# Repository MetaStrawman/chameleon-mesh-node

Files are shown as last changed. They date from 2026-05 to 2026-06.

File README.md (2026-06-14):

# Chameleon Mesh Node

> A rugged, dual-radio environmental telemetry node built on the Meshtastic + LoRa stack.

**Submission:** Seeed Studio Meshtastic Build-Off 2026
**Status:** Design complete & verified — routed, DRC-clean (0 errors / 0 unconnected; 31 cosmetic silkscreen/DFM warnings), Gerbers exported. **Pre-fabrication** (first article not yet ordered).
**Hardware revision:** v1.2
**License:** Multi-license open source — CERN-OHL-S-2.0 (hardware), GPL-3.0-or-later (Meshtastic firmware variant), MIT (tooling). See [`LICENSE`](LICENSE) and [`NOTICE.md`](NOTICE.md).

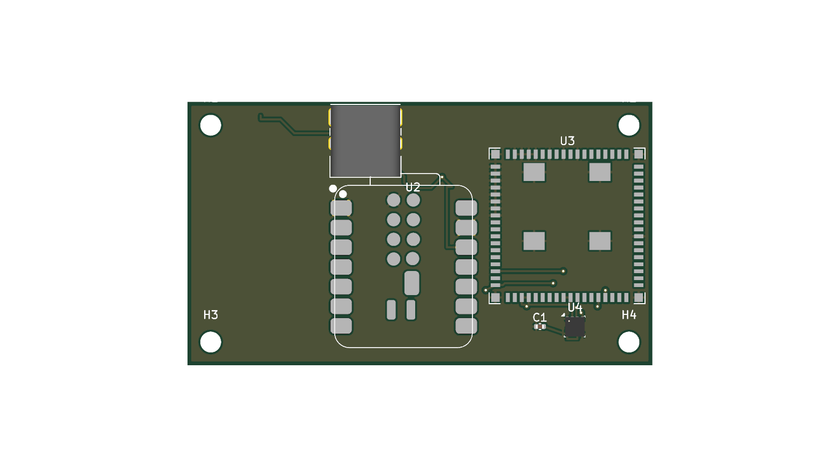
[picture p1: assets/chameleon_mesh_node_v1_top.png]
Chameleon Mesh Node v1.2 — top


*3D render (top). Bottom: [`assets/chameleon_mesh_node_v1_bottom.png`](assets/chameleon_mesh_node_v1_bottom.png).*

## What it is

The Chameleon Mesh Node is a single-board, USB-powered field appliance for Meshtastic telemetry. It joins a Meshtastic mesh on sub-GHz LoRa for resilient long-range messaging, reads local environment with an on-board sensor, and exposes a Wi-Fi / BLE side-channel for short-range provisioning and bulk-data offload.

Designed as a compact, regenerable two-radio Meshtastic reference board.

## Why dual radio

Most off-the-shelf Meshtastic nodes pick one path: a LoRa-only board that needs a phone to provision, or a Wi-Fi-only "smart sensor" that needs an AP within range. Neither survives a real off-grid deployment where the closest infrastructure is hours away.

This board pairs **two complementary radio subsystems on one PCB**:

| Subsystem | Role | Module |
|---|---|---|
| Long-range mesh | Meshtastic LoRa + GNSS time-sync + Wi-Fi scan for opportunistic uplink | Seeed **Wio-WM1110** (Semtech LR1110 + Nordic nRF52840) |
| Local-area + provisioning | Wi-Fi 6 / BLE 5 / 802.15.4 for setup, OTA, and bulk data offload to a passing operator's phone | Seeed **XIAO ESP32-C5** |

Both radios cohabit one 60×34 mm 2-layer board, with explicit RF zoning and a shared ground pour designed to keep mutual desense within acceptable limits for an environmental-sensing-class duty cycle.

## Top-level specs

| | |
|---|---|
| Dimensions | 60 × 34 mm, 2-layer FR-4 |
| MCU | Nordic nRF52840 (Meshtastic firmware host) + Espressif ESP32-C5 (companion) |
| Radios | Semtech LR1110 (sub-GHz LoRa, GNSS, passive Wi-Fi scan); Wi-Fi 6 / BLE 5 / 802.15.4 |
| Power input | USB-C 5 V (XIAO ESP32-C5 onboard port) |
| Environmental sensor | Bosch BME280 (temperature, humidity, barometric pressure, I²C) |
| Operating temperature | -20 °C to +60 °C (designed; pending environmental test) |

## Repository layout

```
chameleon_mesh_node/
├── README.md                — this file
├── LICENSE                  — multi-license map (see also LICENSES/, NOTICE.md)
├── LICENSES/                — full license texts (CERN-OHL-S-2.0, GPL-3.0, MIT)
├── NOTICE.md                — third-party attribution
├── SUBMISSION_CHECKLIST.md  — Build-Off submission readiness gate
├── assets/                  — 3D renders
├── docs/
│   ├── architecture.md      — block diagram, radio zoning, antenna feeds
│   ├── build-guide.md       — BOM, assembly notes, first-power-on checklist
│   └── power-design.md      — USB-C power input and module power tree
├── hardware/
│   ├── kicad/               — KiCad 10 project (schematic, PCB, footprints, gerber zips)
│   ├── gerbers/             — extracted v1.2 Gerbers + Excellon drill (fab-ready)
│   └── scripts/             — Python composers that regenerate schematic + PCB from source
├── firmware/                — Meshtastic nRF52840 variant (variant.h + platformio.ini) + ESP32-C5 stub
└── enclosure/cad/           — 3D-printable case (planned, post-fab)
```

The KiCad project is fully regenerable: `python3 hardware/scripts/build_schematic.py` rebuilds the schematic from the Python composer, and `python3 hardware/scripts/build_pcb.py` rebuilds the pre-placed PCB. You can wipe the `.kicad_*` files and reproduce the design from source.

## How it uses Meshtastic

The Chameleon Mesh Node **is a Meshtastic node.** The Nordic nRF52840 core of the
Wio-WM1110 runs the [Meshtastic firmware](https://github.com/meshtastic/firmware);
the Semtech LR1110 is its sub-GHz LoRa radio (plus GNSS time-sync and passive
Wi-Fi scan). It joins a Meshtastic mesh, announces itself, relays messages, and
publishes its BME280 environmental readings as Meshtastic telemetry — provisioned
over BLE with the standard Meshtastic mobile app.

Because the base board (Seeed Wio-WM1110 / nRF52840 + LR1110) is already supported
upstream, this project ships as an **incremental hardware variant**, not a new port.
The board-specific deltas (BME280 at I²C `0x76`, an ESP32-C5 companion-wake GPIO)
are captured in [`firmware/variant.h`](firmware/variant.h) +
[`firmware/platformio.ini`](firmware/platformio.ini), layered on the upstream
Wio-WM1110 build environment. See [`firmware/README.md`](firmware/README.md).

## Design state & verification

- Schematic ERC: **0 errors / 0 warnings** (KiCad 10).
- PCB: 2-layer routed (top-copper signal, bottom-copper VBUS detour with vias), 3 GND zones poured, RF-zoned placement.
- Post-route DRC: **0 errors / 0 unconnected / 31 warnings** (cosmetic silkscreen-over-pad, silk-to-edge, library-footprint, and one dangling-track advisory; non-blocking for fabrication — see `docs/design-rationale.md`).
- Gerbers + Excellon drill exported (`hardware/gerbers/`).
- v1.1 → v1.2: top edge truncated 60×40 → 60×34 mm so the USB-C mouth is flush with the board edge (the earlier board had the connector inset and the cable could not seat); the DNP BQ24074 charger (U1) and the LiPo connector (J2) were deleted (their dead VBAT traces shorted the relocated mounting hole), leaving the board USB-powered only; mounting holes relocated, routing and GND zones refilled.

## Status

The board is **design-complete and verified** — schematic + ERC clean, RF-zoned
placement, routing and ground pour done, DRC clean (0 errors / 0 unconnected), and
the full fabrication package (gerbers, drill, BOM, placement, schematic PDF, 3D
renders) is exported and committed. This revision is fab-ready.

**Next:** first-article prototype, board bring-up (power smoke test, Meshtastic
flash over SWD, mesh-join test), deep-sleep current measurement, upstreaming the
Meshtastic variant, and an enclosure design.

## License

Multi-license open source — see [`LICENSE`](LICENSE) for the per-component map and
[`LICENSES/`](LICENSES/) for full texts. Hardware: **CERN-OHL-S-2.0**. Meshtastic
firmware variant: **GPL-3.0-or-later**. Tooling/generators: **MIT**. Third-party
components retain their upstream licenses ([`NOTICE.md`](NOTICE.md)).

## Acknowledgments

- **Seeed Studio** for the Wio-WM1110 module, the XIAO ESP32-C5, and the Meshtastic Build-Off platform
- The **Meshtastic** project for the firmware and the mesh protocol
- **Semtech**, **Nordic**, **Espressif**, **Bosch** for the silicon
- **KiCad** for the EDA toolchain (v10.0.3 used)

## Contact

See repository issues for design questions, build reports, or fork notifications.

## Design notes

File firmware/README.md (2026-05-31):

# Firmware

## Meshtastic on the nRF52840 (U3)

The Chameleon Mesh Node v1 hosts the Meshtastic stack on the nRF52840 core of the Wio-WM1110. Upstream:

- Project: https://meshtastic.org/
- Firmware repo: https://github.com/meshtastic/firmware

A hardware variant file specific to this board will be added here once submitted upstream. Until then, the upstream `WM1110_GENERIC_LR1110` variant is a near-fit; the only deviations are the BME280 I²C address (this board uses 0x76, not 0x77) and the ESP32-C5 companion-wake GPIO.

## ESP32-C5 companion firmware

The ESP32-C5 (U2) holds a small UART-bridge + provisioning helper. It is NOT continuously running. It powers on only when the operator presses the user button on the enclosure or when the nRF52840 explicitly toggles the companion-wake GPIO.

A reference companion-firmware build script (PlatformIO `platformio.ini`) will be added here.

## Programming interfaces

| Target | Interface | Connector |
|---|---|---|
| nRF52840 (U3) | SWD | TC2030 (Tag-Connect) footprint on PCB underside |
| ESP32-C5 (U2) | USB-Serial | Onboard via J1 USB-C |
| BME280 (U4) | I²C from U2 | No separate programming interface |

## Bootloader posture

The nRF52840 ships with the Adafruit nRF52 bootloader (DFU-over-USB) pre-installed by Seeed in factory-flashed Wio-WM1110 modules. First-time Meshtastic flash is via SWD using a programmer such as a Black Magic Probe, Segger J-Link EDU, or a generic CMSIS-DAP adapter. Subsequent firmware updates are via the standard Meshtastic OTA path over BLE.

The ESP32-C5 ships with the Espressif ROM bootloader; first flash and all subsequent updates are over USB-C.

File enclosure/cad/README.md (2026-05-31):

# Enclosure — Chameleon Mesh Node v1

Planned post-fab. The enclosure design depends on the final routed PCB and antenna pigtail length, neither of which is locked yet.

Target form factor:

- 3D-printable in ASA or polycarbonate for outdoor UV/weather tolerance
- Vented for the BME280 sensor (one face has a small slot with a Gore-Tex-equivalent membrane)
- Two antenna passthroughs (sealed RP-SMA bulkheads): one for the LoRa whip, one optional for an external 2.4 GHz antenna if the operator chooses a directional Wi-Fi/BLE configuration
- Solar panel mount on the lid: 60 × 40 mm flush-mounted cell pocket with a 4-screw retention pattern
- IP65 minimum gasket-sealed seam
- Battery pocket sized for a single 18650 cell holder OR a flat LiPo pouch up to 60 × 30 × 6 mm

Files (STEP + STL + FreeCAD source) will land here before final fab submission.

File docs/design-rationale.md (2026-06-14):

# Design Rationale & DFM Notes — Chameleon Mesh Node v1.2

This document explains the key layout and manufacturability decisions behind the v1.2 board.
It exists so a reviewer (or a future builder) can see *why* each choice was made, not just *what*
the gerbers show. Target process: standard 2-layer, 1 oz copper, 6 mil (0.15 mm) trace/space.

## Board at a glance
- 60 × 34 mm, 2-layer, USB-C powered, Meshtastic-compatible.
- **U2** — Seeed XIAO ESP32-C5 (MCU + Wi-Fi/BLE + USB-C; the companion/provisioning radio — the Meshtastic host is the nRF52840 inside U3).
- **U3** — Wio-WM1110 LGA-80 module (Semtech LR1110 LoRa + GNSS + Wi-Fi-scan, Nordic nRF52840).
- **J1** — USB-C receptacle, flush at the top edge.
- **C1** — 100 nF 0402 decoupling capacitor at the BME280 VDD (the board's only discrete passive).
- **H1–H4** — M2.5 mounting holes.

*(The schematic is a system block diagram of the functional architecture; board-level passives such as C1 are carried in the fabrication package — BOM, placement, gerbers — not the block diagram.)*

## Placement & clearance decisions

### USB-C ↔ XIAO separation
The USB-C receptacle (J1) is intentionally flush with the top board edge for a clean enclosure
mate. Its through-hole shield/mount tabs project into the board; the XIAO (U2) is placed below it.
We verified that the two **component bodies physically overlapped** (USB-C body extent vs. the XIAO
module outline), not merely their courtyards — so U2 was positioned to give true mechanical clearance
between the connector body and the module. The connecting nets were then re-routed to the relocated
part. This is a real fit fix, not a courtyard waiver.

### Mounting holes — NPTH by design
H1–H4 are **non-plated (NPTH)** M2.5 holes. Plated holes with a copper annulus sat inside the
board-edge keep-out; rather than shrink the pads or move the holes (which constrains the enclosure),
we use bare NPTH holes — the standard, fab-clean solution for edge-adjacent mounting. **Trade-off
acknowledged:** NPTH holes do not provide ground stitching at the corners. They are placed away from
the RF section (H-holes at the board corners; U3 is centred on the right), so there is no impact on
the LoRa return path. For a production revision that wants chassis grounding, a single plated stitch
hole can be added near one corner.

## Power & routing decisions

### VBUS off the top edge (bottom-layer detour)
The USB VBUS rail originally ran along the top edge in the narrow band between the board edge and
J1's pad row — too close to the edge for a robust fab margin. VBUS is re-routed on the **bottom
copper**, passing *under* J1's grounded shield (which provides incidental shielding for the 5 V rail's
inrush/brown-out transients), then via'd up to the XIAO's 5 V input. Net result: comfortable
copper-to-edge clearance with no impact on signal routing.

### USB-C high-density pads
The USB-C connector's own 0.5 mm-pitch pads sit at 0.15 mm clearance — within a standard 6 mil fab
capability, but tighter than the board's conservative default rule. A **scoped design rule** relaxes
clearance to 0.15 mm *only* for the connector's internal pads, leaving the rest of the board on the
conservative default. The XIAO's unused module pads that sit under the connector shield are tied to
GND (they're grounded by the shield anyway), eliminating any net-to-net concern.

## RF integrity (U3 / LoRa)
The Wio-WM1110's RF and antenna routing is **unchanged from the validated reference layout** — none
of the v1.2 manufacturability fixes touched any U3 net (verified: U3-region track counts are identical
before/after). Ground pour continuity under the module and its return path were preserved intact.

## Manufacturing package
The `hardware/kicad/fab_v1.2/` folder is a complete, fab-ready set: RS-274X gerbers (all copper, mask,
silk, paste, adhesive, edge), Excellon drill, pick-and-place (POS), BOM, schematic PDF, and top/bottom
3D renders. The board passes KiCad DRC with **0 errors and 0 unconnected nets**; the remaining 31 warnings
are silkscreen advisories (silk-over-pad, silk-to-edge), footprint-library-link notes, and a single
dangling-track stub — all reviewed and non-blocking for fabrication. The two custom footprints
(Wio-WM1110, XIAO) are vendored under `hardware/kicad/lib/`; standard KiCad library footprints
(USB-C, mounting holes) resolve from a stock KiCad install.

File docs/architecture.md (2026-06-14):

# Architecture — Chameleon Mesh Node v1.2

## Block diagram

```
              ┌─────────────────────────────────────────────────────────┐
              │                                                         │
   USB-C ─────┤ U2 XIAO ESP32-C5 ──(+3V3)──┬───────────────── ANT_24G  │
   (5V in)    │ Wi-Fi 6 / BLE 5 / 802.15.4 │                            │
   J1         │ onboard 3.3 V regulator    │                            │
              │                            ├── U3 Wio-WM1110 ──┬─ ANT_LORA│
              │                            │  LR1110 + nRF52840 ├─ ANT_GNSS│
              │                            │  (Meshtastic host) └─ (Wi-Fi │
              │                            │                      scan)   │
              │                            │                              │
              │                            └── U4 BME280 (I²C, addr 0x76) │
              │                                                         │
              └─────────────────────────────────────────────────────────┘
```

## Why this topology

The nRF52840 inside the Wio-WM1110 hosts the Meshtastic stack. It owns the LoRa radio, the GNSS receiver (LR1110 has both on one die), and the Meshtastic mesh state machine. This is the "always-on" side of the board: it spends most of its life in deep sleep, wakes on radio events or scheduled transmissions, and goes back down.

The ESP32-C5 is the "burst-on" side. It stays in firmware deep-sleep by default. The operator wakes it intentionally during provisioning, OTA firmware updates, or bulk-data offload. Its Wi-Fi 6 / BLE / 802.15.4 stack consumes meaningful current and is gated behind explicit operator intent rather than running continuously.

## Radio zoning

The two antennas are placed at opposite edges of the board with the keep-out and ground pour separating them. The LoRa antenna is on a U.FL pigtail to allow the operator to mount a long whip externally to the enclosure; the 2.4 GHz Wi-Fi/BLE antenna uses a small PCB-trace antenna sized for the ESP32-C5's reference design (close-in coverage is the only requirement).

A shared GND pour on both copper layers provides the return path. Vias stitch the two pours together along the board midline, biased toward the LoRa antenna feed where the cleanest reference is most important.

## I²C bus

The BME280 is the only I²C peripheral in v1, on the ESP32-C5's bus at address 0x76. The bus is exposed at a 0.1" header pad pattern for future expansion (additional sensors, a real-time clock, an OLED display for field provisioning).

## Power tree summary

- Single 5 V input via USB-C (J1)
- The XIAO ESP32-C5 (U2) onboard 3.3 V regulator supplies the +3V3 rail
- +3V3 feeds the Wio-WM1110 (U3) and BME280 (U4) module-internal LDOs
- USB-powered only; no onboard charger, battery connector, or fuel gauge on v1.2

See `power-design.md` for the USB power tree and per-module power notes.

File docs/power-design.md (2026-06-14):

# Power Design — Chameleon Mesh Node v1.2

## Summary

v1.2 is **USB-powered only**. The board takes 5 V from the USB-C port on the
Seeed XIAO ESP32-C5 (J1); the XIAO's onboard regulator supplies the 3.3 V rail
to the rest of the board. The earlier onboard Li-ion charger (TI BQ24074, U1) and
the LiPo battery connector (J2) were already populated DNP and were deleted in
v1.2 — their dead VBAT traces were shorting the relocated mounting hole, and
removing them cleared the short. There is no onboard battery charging, fuel gauge,
or solar input on this revision.

## Power tree

- 5 V enters at the USB-C receptacle (J1) and the XIAO ESP32-C5's VBUS pin.
- The XIAO's onboard 3.3 V regulator feeds the +3V3 rail.
- +3V3 supplies the Wio-WM1110 module (U3) and the BME280 sensor (U4) through
  their module-internal LDOs.

## What v1.2 does NOT have

Considered and deliberately left off this revision:

- Onboard Li-ion charging (the BQ24074 path) — removed; the board runs from USB.
- Battery connector / single-cell LiPo operation — removed with the charger.
- Solar / harvesting input.
- Coulomb-counting fuel gauge or input-current monitor.

## Battery operation (future revision)

A battery-capable revision would re-add a charger (e.g. BQ24074 or MCP73831) and a
JST-PH cell connector on a board outline that keeps the charger's VBAT traces clear
of the mounting holes. That is out of scope for this submission, which targets a
verified, fabbable USB-powered two-radio board.

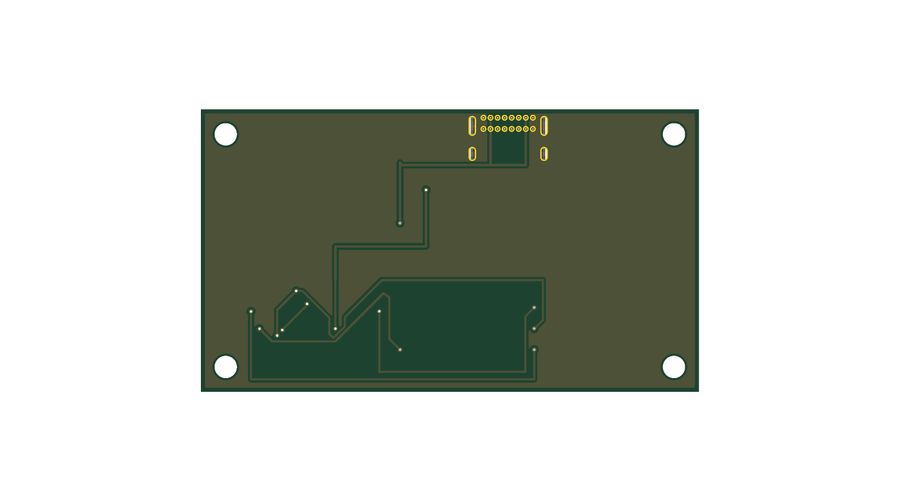
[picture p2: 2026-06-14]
assets/chameleon_mesh_node_v1_bottom.png

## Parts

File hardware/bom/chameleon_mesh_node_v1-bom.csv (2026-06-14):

Refs | Value | Footprint | Qty | DNP
J1 | USB-C Power+Data | Connector_USB:USB_C_Receptacle_GCT_USB4085 | 1
U2 | XIAO-ESP32-C5-SMD | Seeed_XIAO:XIAO-ESP32-C5-SMD | 1
U3 | Wio-WM1110 | ChameleonMeshNode_Custom:Wio_WM1110_LGA80 | 1
U4 | BME280 | Package_LGA:Bosch_LGA-8_2.5x2.5mm_P0.65mm_ClockwisePinNumbering | 1
C1 | 100nF | Capacitor_SMD:C_0402_1005Metric | 1

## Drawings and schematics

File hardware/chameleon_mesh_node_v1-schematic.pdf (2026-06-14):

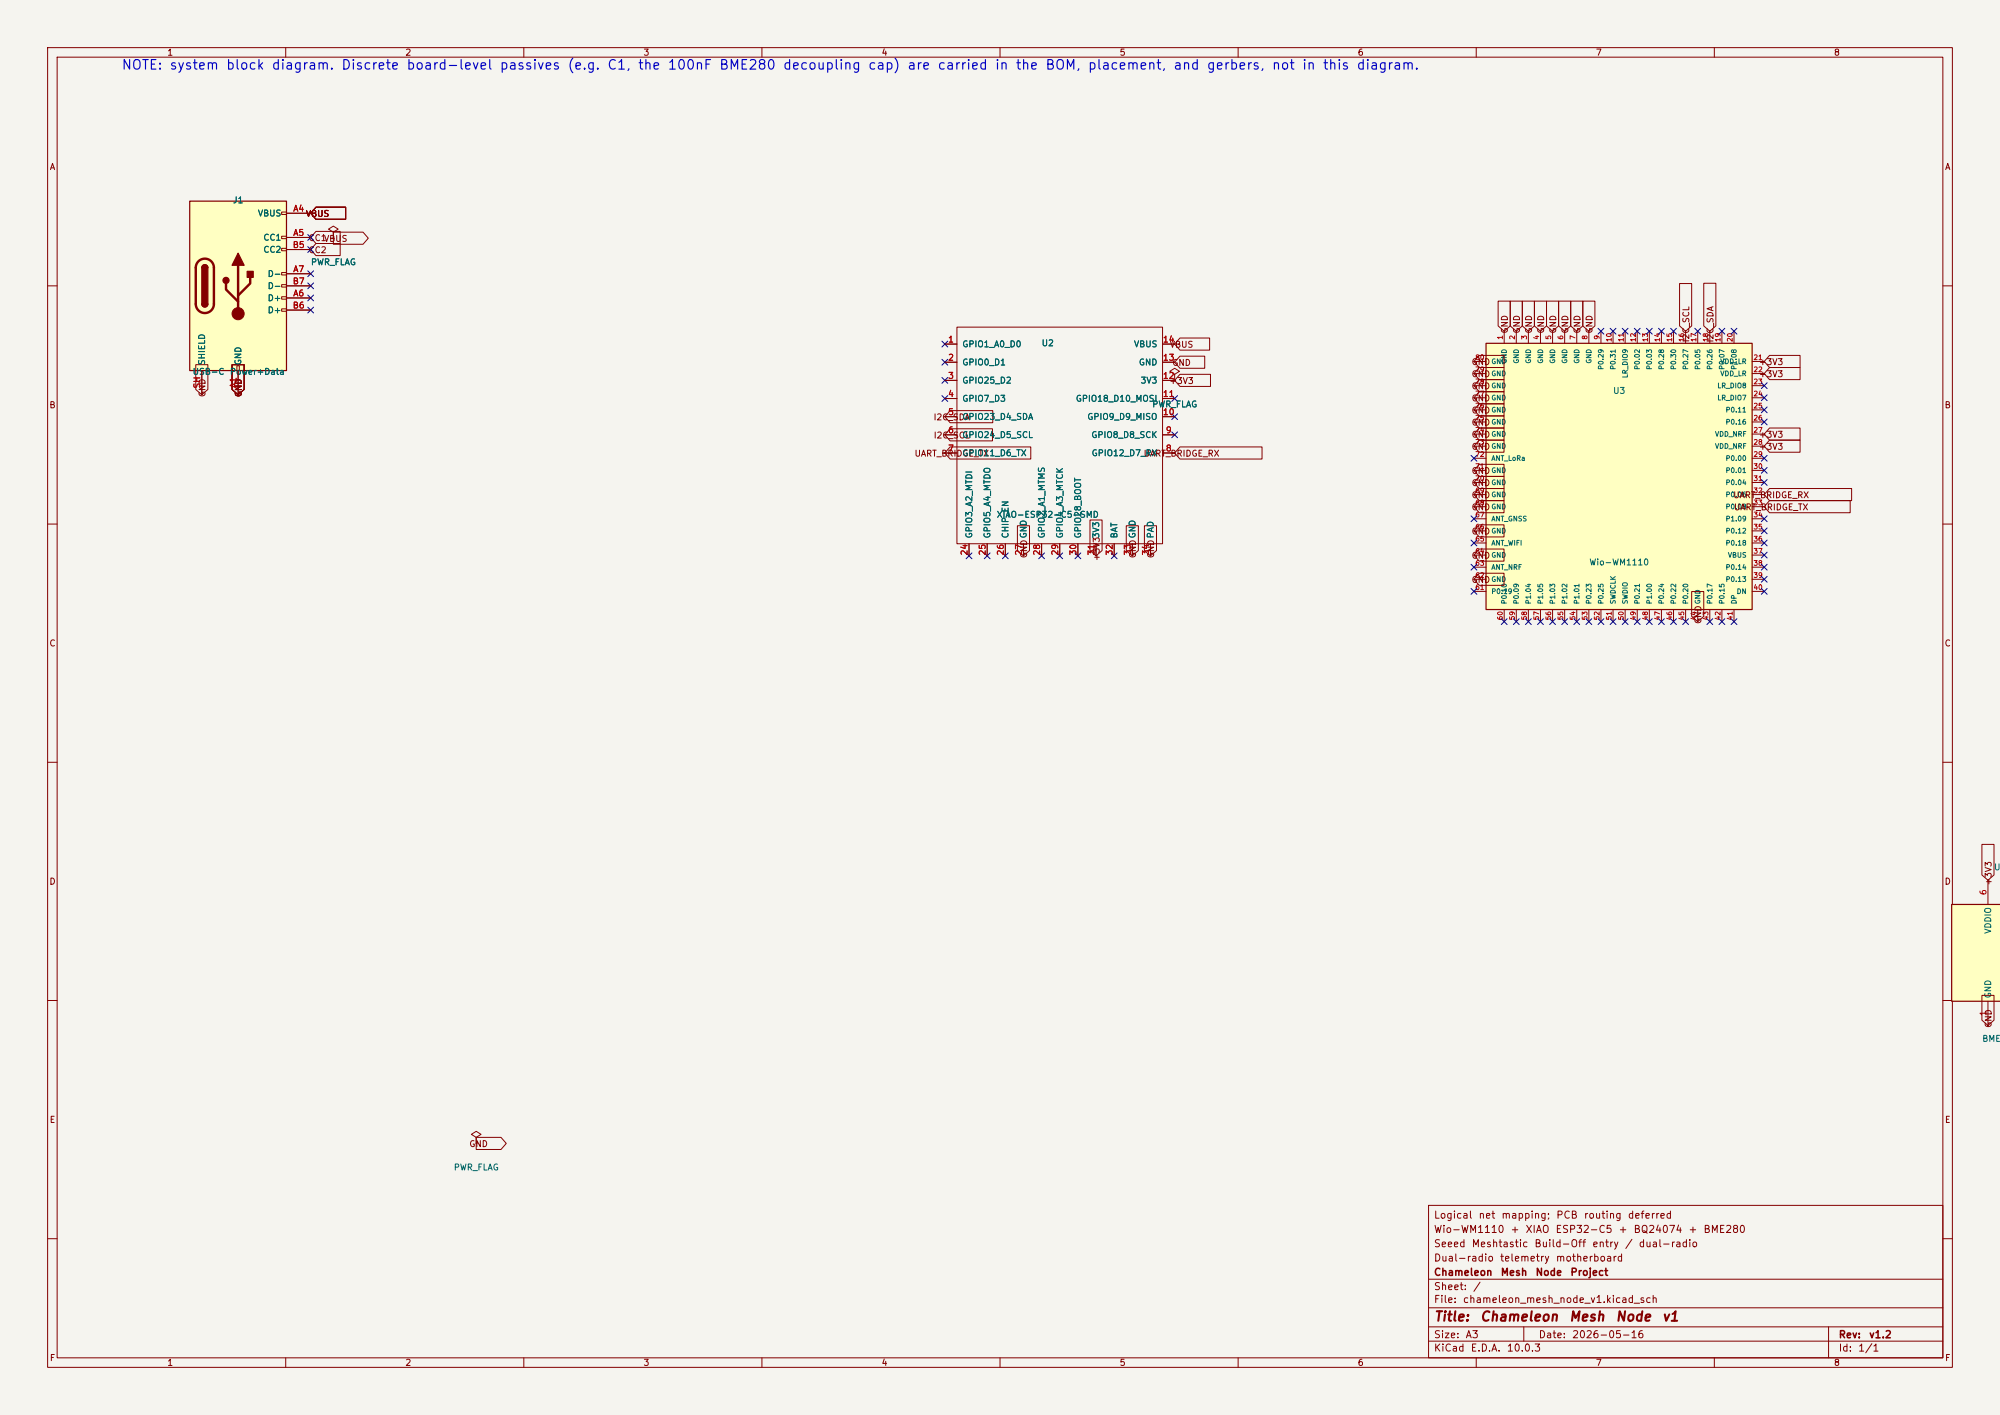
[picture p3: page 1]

NOTE: system block diagram. Discrete board-level passives (e.g. C1, the 100nF BME280 decoupling cap) are carried in the BOM, placement, and gerbers, not in this diagram. PWR_FLAG

J1 USB-C Power+Data GND A1

Logical net mapping; PCB routing deferred GND

Wio-WM1110 + XIAO ESP32-C5 + BQ24074 + BME280
Seeed Meshtastic Build-Off entry / dual-radio
Dual-radio telemetry motherboard
Chameleon Mesh Node Project
Sheet: /
File: chameleon_mesh_node_v1.kicad_sch
Title: Chameleon Mesh Node v1

Size: A3 | Rev: v1.2
KiCad E.D.A. 10.0.3 | Id: 1/1 | F Date: 2026-05-16

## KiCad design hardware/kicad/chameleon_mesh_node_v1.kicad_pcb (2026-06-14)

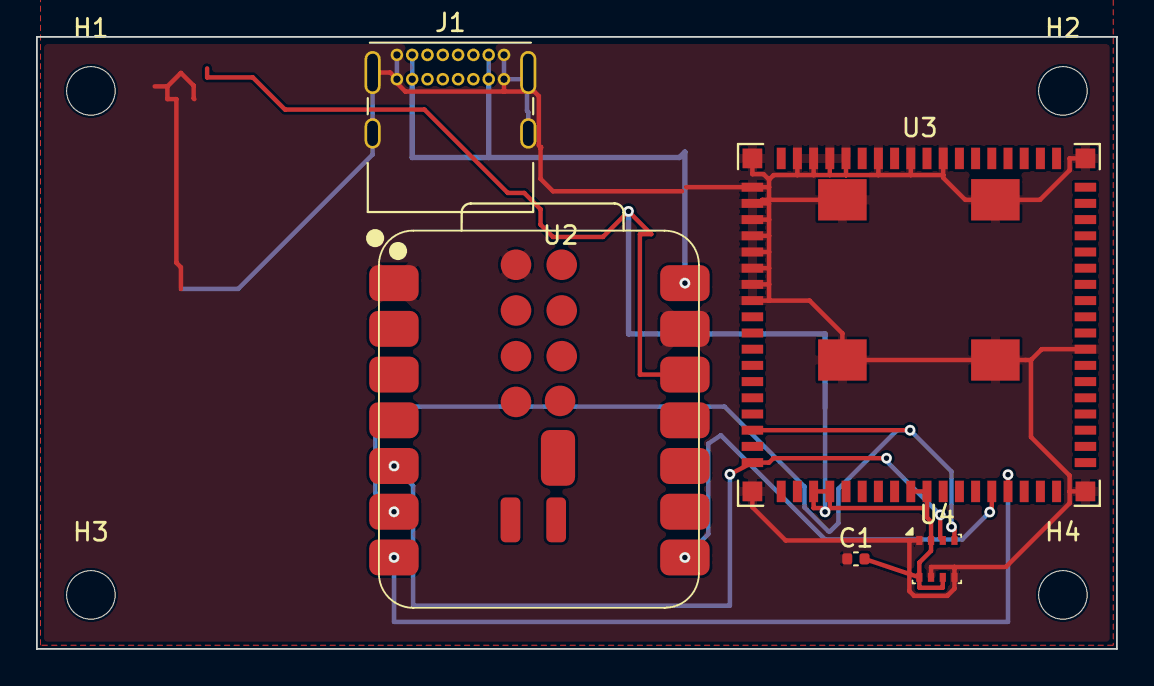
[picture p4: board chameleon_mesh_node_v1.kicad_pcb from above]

Board: 2 copper layers, 60.0 x 34.0 mm, 9 parts (0 on the bottom side), 7 nets.

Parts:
C1: 100nF; C_0402_1005Metric
H1, H2, H3, H4: M2.5; MountingHole_M2.5
J1: USB-C Power+Data; USB_C_Receptacle_GCT_USB4085
U2: XIAO-ESP32-C5-SMD
U3: Wio-WM1110; Wio_WM1110_LGA80
U4: BME280; Bosch_LGA-8_2.5x2.5mm_P0.65mm_ClockwisePinNumbering

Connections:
+3V3: C1.2, U2.12, U3.21, U3.22, U3.27, U3.28, U4.2, U4.6, U4.8
GND: C1.1, J1.A1, J1.A12, J1.B1, J1.B12, J1.SH, U2.1, U2.13, U2.15, U3.1, U3.2, U3.3, U3.4, U3.5, U3.6, U3.7, U3.8, U3.44, U3.62, U3.64, U3.66, U3.68, U3.69, U3.70, U3.71, U3.73, U3.74, U3.75, U3.76, U3.77, U3.78, U3.79, U3.80, U4.1, U4.5, U4.7
I2C_SCL: U2.6, U3.16, U4.4
I2C_SDA: U2.5, U3.18, U4.3
UART_BRIDGE_RX: U2.8, U3.32
UART_BRIDGE_TX: U2.7, U3.33
VBUS: J1.A4, J1.A9, J1.B4, J1.B9, U2.14

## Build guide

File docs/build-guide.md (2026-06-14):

# Build Guide — Chameleon Mesh Node v1.2

## BOM

| Ref | Part | Package | Manufacturer P/N | Source |
|---|---|---|---|---|
| U2 | ESP32-C5 SoM (Wi-Fi 6 / BLE / 802.15.4) | XIAO SMD | Seeed XIAO-ESP32-C5 | Seeed Studio |
| U3 | LR1110 LoRa+GNSS + nRF52840 module | LGA-80 | Seeed Wio-WM1110 | Seeed Studio |
| U4 | Environmental sensor (T/H/P) | LGA-8 | Bosch BME280 | DigiKey / Mouser |
| J1 | USB-C receptacle (power + data) | SMD | GCT USB4085 (or equiv.) | LCSC |
| C1 | 100 nF decoupling cap (BME280 VDD) | 0402 | generic X7R 16V | LCSC |
| (passives) | Caps, resistors, ferrite beads | 0402 / 0603 | various | — |
| Antennas | LoRa whip (U.FL pigtail) + on-board 2.4 GHz trace | — | varies | — |

A consolidated CSV BOM is in `hardware/bom/`. Power is module-integrated (the XIAO ESP32-C5 and Wio-WM1110 carry their own regulation and decoupling); the one discrete part is **C1, a 100 nF 0402 decoupling capacitor at the BME280 VDD** (Bosch datasheet). The schematic is a system block diagram and abstracts board-level passives — C1 appears in the BOM, placement, and gerbers.

## First power-on checklist

1. **Visual inspect** — verify no solder bridges around the LGA-80 (U3, Wio-WM1110) and the XIAO ESP32-C5 (U2). U3 is the densest package.
2. **Power smoke test** — apply 5 V via the USB-C port. Verify the +3V3 rail sits at 3.3 V ± 0.1 V (XIAO ESP32-C5 onboard regulator). Total current draw should be < 30 mA with both modules in their default boot state.
3. **First firmware** — flash the Meshtastic nRF52840 variant onto U3 via the SWD pads (a TC2030-style tag-connect footprint is on the PCB; no connector is populated — programming uses a pogo-pin clip). See `firmware/` for the device-specific configuration overlay.
4. **Companion** — flash the ESP32-C5 stub firmware via USB-C (no separate programmer needed; the C5 has built-in USB-Serial). See `firmware/`.
5. **Mesh join test** — provision the node onto a Meshtastic mesh via the official mobile app over BLE. Verify it announces itself and receives messages.

## Reflow profile

Standard lead-free reflow, peak 245 °C, 60-90 s above 217 °C. Pre-heat ramp 1.5 °C/s. The LR1110 inside the WM1110 has the usual ROHS reflow tolerance; do not exceed 250 °C peak.

## Assembly notes

- The Wio-WM1110 has a metal RF shield on the underside facing the PCB. Make sure your stencil aperture for the module's GND pad is correctly sized; under-paste here causes RF coupling issues.
- The XIAO ESP32-C5's USB-C testpoints under the module are NOT a programming interface — they are factory test only. Program through the J1 USB-C connector.
- BME280 is sensitive to airflow direction. Position the enclosure vent so airflow crosses the sensor's metal lid, not the side openings.

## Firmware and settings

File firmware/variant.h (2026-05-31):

// SPDX-License-Identifier: GPL-3.0-or-later
//
// Chameleon Mesh Node v1 — Meshtastic hardware variant (nRF52840 + LR1110)
// Host: Nordic nRF52840 core of the Seeed Wio-WM1110 (Semtech LR1110).
//
// STATUS: stub / work-in-progress. This board is electrically a close
// relative of the upstream Seeed Wio-WM1110 variant, so the LR1110 radio,
// GNSS, and SPI wiring are INHERITED from that upstream variant and are NOT
// redefined here. Only the two board-specific deviations are expressed below.
// Build by applying this variant on top of the upstream base env
// (see platformio.ini) — do not treat these defines as a complete pinmap.
//
// Upstream base:  meshtastic/firmware  variant  WM1110_GENERIC_LR1110
//                 (https://github.com/meshtastic/firmware)
//
// Board deviations from the upstream Wio-WM1110 reference:
//   1. On-board BME280 environmental sensor at I2C address 0x76 (not 0x77).
//   2. ESP32-C5 companion-wake GPIO (nRF drives this line to power the
//      XIAO ESP32-C5 only for provisioning / OTA / bulk offload).
//
// Pin facts confirmed from this board's netlist (nRF52840 P-port numbering):
//   I2C0  SDA = P0.26   SCL = P0.27   (BME280 + any expansion)
//   UART  TX  = P0.06   RX  = P0.08   (companion link to ESP32-C5)
// All LR1110 SPI / BUSY / RESET / DIO / GNSS / RF-switch lines: inherited
// from the upstream WM1110 variant (module-internal, fixed by the WM1110).

#pragma once

// --- Environmental sensor (board deviation #1) -----------------------------
#define HAS_BME280            1
#define BME_280_ADDR          0x76   // this board straps SDO low

// --- Companion ESP32-C5 wake line (board deviation #2) ----------------------
// Define to the actual nRF GPIO once the net is pulled from the schematic.
// #define PIN_COMPANION_WAKE  (0 + NN)

// --- Confirmed I2C / UART pins (see header note) ----------------------------
#define I2C_SDA               (0 + 26)   // P0.26
#define I2C_SCL               (0 + 27)   // P0.27
#define PIN_SERIAL2_TX        (0 + 6)    // P0.06  -> ESP32-C5
#define PIN_SERIAL2_RX        (0 + 8)    // P0.08  <- ESP32-C5

// NOTE: radio (LR1110), GNSS, button, LED, battery-sense, and SWD defines are
// supplied by the upstream WM1110_GENERIC_LR1110 variant and intentionally
// omitted here to avoid divergence. See SUBMISSION_CHECKLIST.md for the
// remaining bring-up tasks before this variant is upstreamed.

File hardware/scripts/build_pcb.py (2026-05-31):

#!/usr/bin/env python3
"""Compose chameleon_mesh_node_v1.kicad_pcb with all 6 footprints
pre-placed inside the 60x40 mm outline + 4 corner M2.5 mounting holes.

Strategy mirrors build_schematic.py:
  * For each placement, read the source .kicad_mod, embed it inline
    inside a (footprint ...) block at (X, Y, rotation) on F.Cu.
  * Assign net numbers + net names to each pad by looking up the
    (ref, pad_number) tuple in the schematic's NETS table.
  * Build the net table at the top of the PCB so it agrees with the
    schematic's net list.

TWO KEY LESSONS from the 2026-05-16 debug session — both caused
silent "Failed to load board" without any parser diagnostic:

1. LAYER ORDER must be KiCad's functional grouping, NOT strict
   numeric-ascending by ID. The canonical sequence is:
     F.Cu, B.Cu  (copper, signal)
     F.Adhes, B.Adhes  (mechanical)
     F.Paste, B.Paste  (stencil)
     F.SilkS, B.SilkS  (silkscreen)
     F.Mask, B.Mask    (solder mask)  ← IDs 1/3 come AFTER 5/7
     Dwgs/Cmts/Eco1/Eco2.User
     Edge.Cuts, Margin
     F.CrtYd, B.CrtYd  ← F first (31 before 29)
     F.Fab, B.Fab      ← F first (35 before 33)

2. NO LISP-STYLE COMMENTS (`;` or `;;`) anywhere in the file. The
   .kicad_pcb parser silently crashes on the first one. The earlier
   `;; Board outline 60x40 mm` comment was the final smoking gun;
   removing it made the composer work after a 90-min hunt. Use
   `(comment N "...")` inside `(title_block ...)` for human notes
   instead, or just leave the section unannotated.

After opening in Pcbnew, the operator only needs to: route the ratlines,
add a GND pour, run DRC, export gerbers. No drag-from-origin pass needed.

Run:
  python3 scripts/build_pcb.py
  kicad-cli pcb drc chameleon_mesh_node_v1.kicad_pcb   # verification
"""
from __future__ import annotations

import re
import uuid
from pathlib import Path
from typing import NamedTuple

# Reuse the schematic's NETS + NO_CONNECT_PINS + Placement type so this
# composer never drifts from the schematic netlist.
import sys
sys.path.insert(0, str(Path(__file__).parent))
from build_schematic import NETS, PLACEMENTS as SCH_PLACEMENTS, NO_CONNECT_PINS

PROJ        = Path(__file__).resolve().parent.parent / "kicad"
KICAD_SHARE = Path("/usr/share/kicad/footprints")
OUT_PCB     = PROJ / "chameleon_mesh_node_v1.kicad_pcb"

# ── Footprint sources (must match the schematic placements' footprint field)
FP_SOURCES: dict[str, Path] = {
    "Connector_USB:USB_C_Receptacle_GCT_USB4085":
        KICAD_SHARE / "Connector_USB.pretty" / "USB_C_Receptacle_GCT_USB4085.kicad_mod",
    "Package_DFN_QFN:QFN-16-1EP_3x3mm_P0.5mm_EP1.675x1.675mm":
        KICAD_SHARE / "Package_DFN_QFN.pretty" / "QFN-16-1EP_3x3mm_P0.5mm_EP1.675x1.675mm.kicad_mod",
    "Connector_JST:JST_PH_S2B-PH-K_1x02_P2.00mm_Horizontal":
        KICAD_SHARE / "Connector_JST.pretty" / "JST_PH_S2B-PH-K_1x02_P2.00mm_Horizontal.kicad_mod",
    "Seeed_XIAO:XIAO-ESP32-C5-SMD":
        PROJ / "lib" / "Seeed_XIAO.pretty" / "XIAO-ESP32-C5-SMD.kicad_mod",
    "ChameleonMeshNode_Custom:Wio_WM1110_LGA80":
        PROJ / "lib" / "ChameleonMeshNode_Custom.pretty" / "Wio_WM1110_LGA80.kicad_mod",
    "Package_LGA:Bosch_LGA-8_2.5x2.5mm_P0.65mm_ClockwisePinNumbering":
        KICAD_SHARE / "Package_LGA.pretty" / "Bosch_LGA-8_2.5x2.5mm_P0.65mm_ClockwisePinNumbering.kicad_mod",
}

# ── PCB placement coordinates (mm) — chosen for RF zoning:
#   Wio (LR1110/nRF) on right edge, antennas pointing to board right
#   BQ24074 switcher kept far from both radios
#   BME280 in bottom-right corner, away from RF + thermal sources
#   USB-C + LiPo on opposite vertical edges
class PCBPlacement(NamedTuple):
    ref: str
    x: float
    y: float
    rotation: int   # degrees, KiCad convention

PCB_PLACEMENTS: list[PCBPlacement] = [
    PCBPlacement("J1", 20.0,  7.0,    0),   # USB-C top edge, opening upward
    PCBPlacement("U1", 8.0,   8.0,    0),   # BQ24074 left of USB-C
    PCBPlacement("J2", 8.0,  22.0,   90),   # LiPo JST left edge, cable exits up
    PCBPlacement("U2", 26.0, 22.0,    0),   # XIAO center
    PCBPlacement("U3", 47.0, 22.0,   90),   # Wio LGA-80 right side, antennas → right edge
    PCBPlacement("U4", 50.0, 35.0,    0),   # BME280 bottom-right
]

# ── Mounting holes (M2.5, 3 mm from each corner)
MOUNTING_HOLES = [
    ("H1", 3.0,  3.0),
    ("H2", 57.0, 3.0),
    ("H3", 3.0,  37.0),
    ("H4", 57.0, 37.0),
]


# ── Helpers ───────────────────────────────────────────────────────────
def slurp(path: Path) -> str:
    return path.read_text(encoding="utf-8", errors="replace")

def strip_footprint_wrapper(text: str) -> str:
    """Drop the outer `(footprint NAME ...)` wrapper, return the inner content.
    Lets us re-wrap at our chosen placement coordinates."""
    # Find the opening paren of `(footprint ...)`
    m = re.search(r'\(footprint\s+\S+[^\n]*', text)
    if not m:
        raise ValueError("no (footprint ...) wrapper found")
    start = m.end()
    # Walk balanced parens from the opening of (footprint to find its close.
    depth = 1   # we're inside the (footprint ...
    j = m.start() + len('(footprint')
    # Re-scan from start to count parens properly.
    depth = 0
    j = 0
    in_string = False
    fp_open = -1
    while j < len(text):
        c = text[j]
        if c == '"' and (j == 0 or text[j-1] != '\\'):
            in_string = not in_string
        elif not in_string:
            if c == '(':
                if depth == 0 and text[j:j+len('(footprint')] == '(footprint':
                    fp_open = j
                depth += 1
            elif c == ')':
                depth -= 1
                if depth == 0 and fp_open >= 0:
                    inner = text[fp_open + len('(footprint'):j]
                    return inner
        j += 1
    raise ValueError("unbalanced parens")

def renumber_pad_nets(inner: str, ref: str, net_map: dict[str, tuple[int, str]]) -> str:
    """Rewrite each `(pad "PADNUM" ...)` block to include `(net N "name")`.
    Pad blocks that have no net mapping get `(net 0 "")` (unconnected)."""
    # Match a pad opening and find its closing paren.
    out: list[str] = []
    i = 0
    while i < len(inner):
        m = re.search(r'\(pad\s+"?([^\s")]+)"?', inner[i:])
        if not m:
            out.append(inner[i:])
            break
        rel = m.start()
        out.append(inner[i:i+rel])
        # Find matching close-paren for THIS (pad block.
        depth = 0
        j = i + rel
        in_string = False
        start = j
        pad_num = m.group(1).strip('"')
        while j < len(inner):
            c = inner[j]
            if c == '"' and (j == 0 or inner[j-1] != '\\'):
                in_string = not in_string
            elif not in_string:
                if c == '(':
                    depth += 1
                elif c == ')':
                    depth -= 1
                    if depth == 0:
                        # End of pad block at j (inclusive). Insert net just
                        # before the closing paren.
                        pad_body = inner[start:j]
                        net_idx, net_name = net_map.get(pad_num, (0, ""))
                        # Strip any existing (net ...) inside the pad body.
                        pad_body = re.sub(r'\(net\s+\d+\s+"[^"]*"\)\s*', '', pad_body)
                        # Append (net N "name") right before the close.
                        new_pad = pad_body + f'\n      (net {net_idx} "{net_name}")\n    )'
                        out.append(new_pad)
                        i = j + 1
                        break
            # j MUST increment outside the if/elif so quote chars + chars-inside-strings
            # also advance. (Earlier version had this inside the elif → infinite loop on
            # the first " encountered inside a pad block.)
            j += 1
        else:
            # Unterminated; bail.
            out.append(inner[i+rel:])
            break
    return "".join(out)


# ── Compose ───────────────────────────────────────────────────────────
def build():
    # 1. Build net table — gather all unique net names from NETS.
    net_names = sorted({net for _, _, net in NETS})
    # net 0 is the unconnected/default
    nets = ["(net 0 \"\")"] + [f'(net {i+1} "{name}")' for i, name in enumerate(net_names)]
    net_index = {name: i + 1 for i, name in enumerate(net_names)}

    # 2. Build per-ref pad→net mapping.
    per_ref_pad_nets: dict[str, dict[str, tuple[int, str]]] = {}
    for ref, pad_num, net_name in NETS:
        per_ref_pad_nets.setdefault(ref, {})[pad_num] = (net_index[net_name], net_name)

    # 3. For each placement, embed the footprint with patched pad nets.
    fp_blocks: list[str] = []
    sch_by_ref = {p.ref: p for p in SCH_PLACEMENTS}
    for pp in PCB_PLACEMENTS:
        sch = sch_by_ref[pp.ref]
        fp_lib_id = sch.footprint
        src = FP_SOURCES.get(fp_lib_id)
        if not src or not src.is_file():
            raise SystemExit(f"FATAL: footprint source missing for {fp_lib_id}: {src}")
        inner = strip_footprint_wrapper(slurp(src))
        # Strip leading footprint-name string (e.g. ' "Bosch_LGA-8..."') —
        # strip_footprint_wrapper kept everything after `(footprint`, including
        # the name token. Match optional whitespace + a quoted-or-unquoted name.
        inner = re.sub(r'^\s*"[^"]*"\s*', '', inner)         # quoted name
        inner = re.sub(r'^\s*[^\s()]+\s*',  '', inner)        # unquoted name (fallback)
        # Drop top-level wrapper metadata that ONLY belongs at the original
        # .kicad_mod root, not when embedded inline in a .kicad_pcb. Each
        # of these blocks is single-line so a non-greedy paren match is safe.
        for pat in (
            r'\(version\s+\d+\)\s*',
            r'\(generator\s+"[^"]*"\)\s*',
            r'\(generator_version\s+"[^"]*"\)\s*',
            r'\(layer\s+"[^"]*"\)\s*',
            r'\(tedit\s+\S+\)\s*',
        ):
            inner = re.sub(pat, '', inner, count=1)
        # Don't strip the source's (property "Reference"/"Value") blocks —
        # KiCad parser is order-sensitive and expects them BETWEEN
        # descr/tags and attr. Instead, in-place swap the value strings.
        # Bundled source default: "Reference" "REF**", "Value" "<footprint_name>"
        inner = re.sub(r'\(property\s+"Reference"\s+"[^"]*"',
                       f'(property "Reference" "{pp.ref}"', inner, count=1)
        inner = re.sub(r'\(property\s+"Value"\s+"[^"]*"',
                       f'(property "Value" "{sch.value}"', inner, count=1)
        # Rewrite pad nets.
        inner = renumber_pad_nets(inner, pp.ref, per_ref_pad_nets.get(pp.ref, {}))
        fp_uuid = str(uuid.uuid4())
        fp_blocks.append(
            f'(footprint "{fp_lib_id}"\n'
            f'  (layer "F.Cu")\n'
            f'  (uuid "{fp_uuid}")\n'
            f'  (at {pp.x} {pp.y} {pp.rotation})\n'
            f'{inner}\n'
            f')'
        )

    # 4. Mounting holes — hand-authored inline (avoids the broken
    #    KiCad-bundled MountingHole.pretty reference from my earlier
    #    attempt).
    for ref, mx, my in MOUNTING_HOLES:
        h_uuid = str(uuid.uuid4())
        fp_blocks.append(
            f'(footprint "ChameleonMeshNode_Custom:MountingHole_M2.5"\n'
            f'  (layer "F.Cu")\n'
            f'  (uuid "{h_uuid}")\n'
            f'  (at {mx} {my} 0)\n'
            f'  (attr through_hole)\n'
            f'  (property "Reference" "{ref}"\n'
            f'    (at 0 -3.5 0) (layer "F.SilkS")\n'
            f'    (uuid "{uuid.uuid4()}")\n'
            f'    (effects (font (size 1 1) (thickness 0.15)))\n'
            f'  )\n'
            f'  (property "Value" "M2.5"\n'
            f'    (at 0 3.5 0) (layer "F.Fab")\n'
            f'    (uuid "{uuid.uuid4()}")\n'
            f'    (effects (font (size 1 1) (thickness 0.15)))\n'
            f'  )\n'
            f'  (pad "" thru_hole circle\n'
            f'    (at 0 0)\n'
            f'    (size 5.5 5.5)\n'
            f'    (drill 2.7)\n'
            f'    (layers "*.Cu" "*.Mask")\n'
            f'    (uuid "{uuid.uuid4()}")\n'
            f'  )\n'
            f')'
        )

    # 5. Assemble the file.
    pcb = f'''(kicad_pcb
\t(version 20240108)
\t(generator "kicad-python")
\t(generator_version "10.0")
\t(general (thickness 1.6) (legacy_teardrops no))
\t(paper "A4")
\t(title_block
\t\t(title "Chameleon Mesh Node v1 — PCB")
\t\t(date "2026-05-16")
\t\t(rev "v1.0-DRAFT")
\t\t(company "Chameleon Mesh Node Project")
\t\t(comment 1 "Pre-placed: USB-C+BQ24074 top, LiPo left, XIAO center, Wio right (antennas to edge), BME280 bottom-right")
\t\t(comment 2 "Routing + GND pour pending operator GUI")
\t)
\t(layers
\t\t(0 "F.Cu" signal)
\t\t(2 "B.Cu" signal)
\t\t(9 "F.Adhes" user "F.Adhesive")
\t\t(11 "B.Adhes" user "B.Adhesive")
\t\t(13 "F.Paste" user)
\t\t(15 "B.Paste" user)
\t\t(5 "F.SilkS" user "F.Silkscreen")
\t\t(7 "B.SilkS" user "B.Silkscreen")
\t\t(1 "F.Mask" user)
\t\t(3 "B.Mask" user)
\t\t(17 "Dwgs.User" user "User.Drawings")
\t\t(19 "Cmts.User" user "User.Comments")
\t\t(21 "Eco1.User" user "User.Eco1")
\t\t(23 "Eco2.User" user "User.Eco2")
\t\t(25 "Edge.Cuts" user)
\t\t(27 "Margin" user)
\t\t(31 "F.CrtYd" user "F.Courtyard")
\t\t(29 "B.CrtYd" user "B.Courtyard")
\t\t(35 "F.Fab" user)
\t\t(33 "B.Fab" user)
\t)
\t(setup (pad_to_mask_clearance 0))

\t{chr(10).join(nets)}

\t(gr_line (start 0 0)   (end 60 0)  (stroke (width 0.1) (type default)) (layer "Edge.Cuts") (uuid "{uuid.uuid4()}"))
\t(gr_line (start 60 0)  (end 60 40) (stroke (width 0.1) (type default)) (layer "Edge.Cuts") (uuid "{uuid.uuid4()}"))
\t(gr_line (start 60 40) (end 0 40)  (stroke (width 0.1) (type default)) (layer "Edge.Cuts") (uuid "{uuid.uuid4()}"))
\t(gr_line (start 0 40)  (end 0 0)   (stroke (width 0.1) (type default)) (layer "Edge.Cuts") (uuid "{uuid.uuid4()}"))

{chr(10).join(fp_blocks)}
)
'''
    OUT_PCB.write_text(pcb)
    print(f"wrote: {OUT_PCB}")
    print(f"  {len(PCB_PLACEMENTS)} components pre-placed")
    print(f"  {len(MOUNTING_HOLES)} mounting holes")
    print(f"  {len(net_names)} named nets + 1 unconnected")


if __name__ == "__main__":
    build()

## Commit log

2026-05-31 Chameleon Mesh Node v1.0 — Seeed Meshtastic Build-Off 2026 submission
    Dual-radio off-grid telemetry node: Wio-WM1110 (LoRa + GNSS + BLE) + XIAO ESP32-C5 (Wi-Fi 6 / BLE 5 / 802.15.4), solar/LiPo power. DRC-clean 2-layer board, Gerbers + KiCad source + firmware variant +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
    [chameleon_mesh_node_v1-B_Cu.gbl, chameleon_mesh_node_v1-B_Mask.gbs, chameleon_mesh_node_v1-B_Paste.gbp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]
2026-05-31 hardware: v1.1 DRC fix — resolve U2/J1 collision, 0 errors / 0 unconnected
    Reposition U2 (XIAO) clear of the J1 USB-C connector and re-route the affected
    signal/power nets (I2C SDA/SCL, UART bridge TX/RX, +3V3, VBUS) with the GND
    pour left intact, then correct the over-strict intra-connector and hole-edge
    clearance flags. Board now passes DRC at error severity with 0 violations and
    0 unconnected items under JLCPCB 2-layer rules.
    Re-exported gerbers + Excellon drill, regenerated hardware/kicad/gerbers_v11.zip,
    README status updated to v1.1.
    [chameleon_mesh_node_v1-B_Courtyard.gbr, chameleon_mesh_node_v1-B_Cu.gbl, chameleon_mesh_node_v1-B_Fab.gbr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]
2026-06-01 hardware: publish corrected v1.1 60x35 board (USB-C edge fix)
    Replace the 60x40 board + gerbers + renders with the truncated 60x35
    revision that actually fixes the USB-C cable-insertion blocker (board
    top edge moved flush to the receptacle face; H1/H2 relocated inside the
    new outline; GND pour refilled). Regenerated gerbers + Excellon drill +
    3D renders from the corrected board via kicad-cli; README/docs
    reconciled from the old "U2-reposition" narrative to the truncation fix;
    stale v1.0 gerber zip removed. OPSEC-clean (no Argus/PII).
    [chameleon_mesh_node_v1-B_Courtyard.gbr, chameleon_mesh_node_v1-B_Cu.gbl, chameleon_mesh_node_v1-B_Fab.gbr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]
2026-06-01 hardware: add BOM + position file + schematic PDF; checklist sync
    Generated hardware/bom/{*-bom.csv,*-pos.csv} and *-schematic.pdf via
    kicad-cli from the OPSEC-clean public source (not the monorepo, which
    carries internal identifiers in title blocks). Closes the missing
    BOM/POS/schematic submission gap. SUBMISSION_CHECKLIST synced: public
    repo + copyright + BOM items marked done.
    [chameleon_mesh_node_v1-bom.csv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]
2026-06-06 hardware: v1.1 USB-powered fab package — verified board (0 shorts), DNP U1/J2
    - Replace stale published board (had 2 shorts / 136 DRC errors) with the
    verified board: 0 unconnected, 0 shorts, fully routed (11 nets, 210 traces,
    2 GND pours); 29 remaining DRC items are benign USB-C-pitch/edge/thermal DFM noise.
    - Regenerate all gerbers + drill from the verified board.
    - Add hardware/kicad/fab_v1.1_usbpwr/: ready-to-fab ZIP, DNP-aware positions,
    top render, and fab README.
    - +3V3 over-voltage fixed by DNP U1 (BQ24074 charger) + J2 (battery): board is a
    USB-powered LoRa + GNSS + sensor node.
    [board-B_Adhesive.gbr, board-B_Courtyard.gbr, board-B_Cu.gbr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]
2026-06-14 hardware: v1.2 USB-flush board — replace v1.1, add BME280 decoupling
    v1.2 fixes the USB-C-can't-seat defect: the top edge is truncated 60x40 -> 60x34
    so the connector mouth is flush with the board edge. The DNP BQ24074 charger (U1)
    and the LiPo connector (J2) are removed (their dead VBAT traces shorted the
    relocated mounting hole), so the board is USB-powered only. Mounting holes moved
    into the new outline.
    - Added C1, a 100nF 0402 decoupling cap at the BME280 VDD (placed + routed to
    +3V3, GND via the ground pour).
    - Schematic reconciled to the board (U1/J2 + battery nets removed); ERC 0/0.
    The schematic is a system block diagram; board-level passives (C1) are carried
    in the BOM, pl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
    [board-B_Adhesive.gbr, board-B_Courtyard.gbr, board-B_Cu.gbr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]
